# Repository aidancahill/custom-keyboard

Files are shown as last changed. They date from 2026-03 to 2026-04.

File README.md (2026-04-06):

# custom-keyboard

A 54-key split ergonomic keyboard with analog joysticks, shift register matrix scanning, and a Seeeduino XIAO nRF52840 BLE microcontroller. Designed from scratch using Ergogen, KiCad, and ZMK firmware.

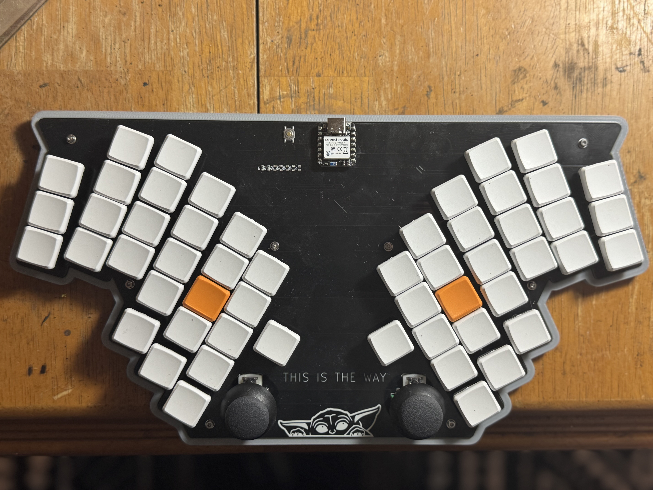
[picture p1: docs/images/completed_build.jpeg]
Completed Build

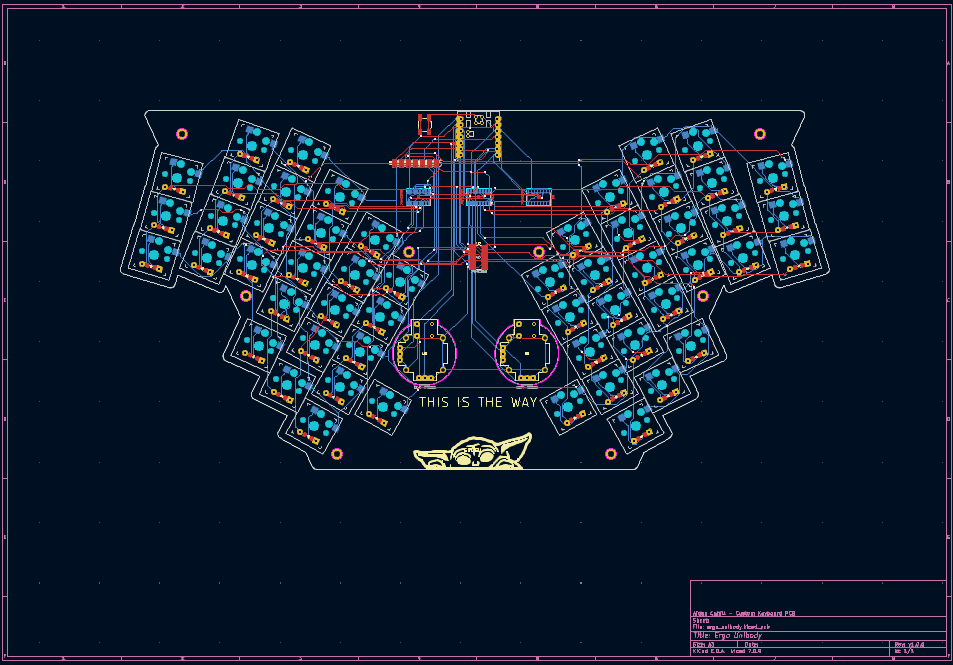
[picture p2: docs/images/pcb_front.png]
PCB Front

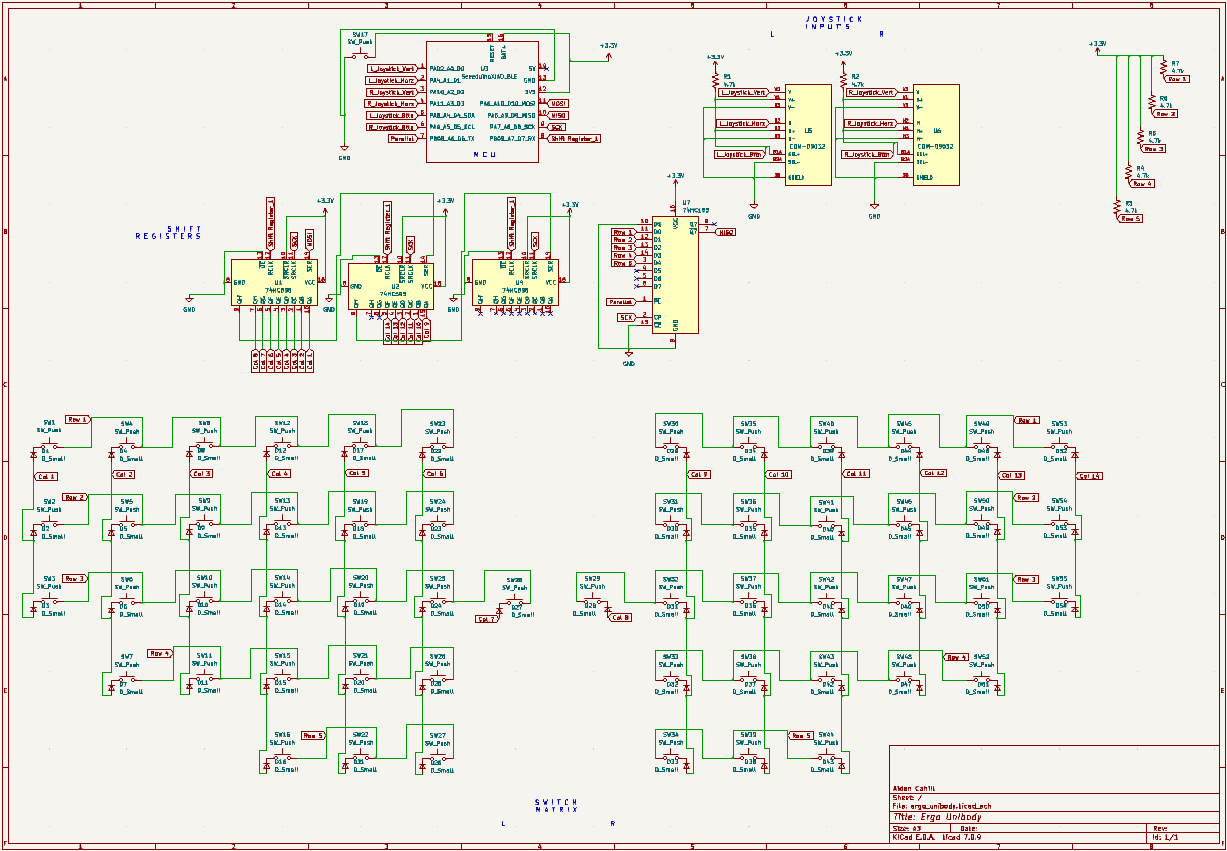
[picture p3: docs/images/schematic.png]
Schematic


## Features

- 54 Kailh Choc V1 low-profile keys with hotswap sockets
- Split ergonomic layout with column stagger and splay
- 2× analog joysticks (mouse movement + scroll)
- 74HC595 shift registers for column scanning (3× SIPO)
- 74HC165 shift register for row reading (1× PISO)
- Seeeduino XIAO nRF52840 BLE MCU
- 3D printed case with integrated bottom plate and heat-set inserts
- Custom Grogu silkscreen art

## Layout

```
Left half:                              Right half:
+---+---+---+---+---+---+              +---+---+---+---+---+---+
|Esc| 1 | 2 | 3 | 4 | 5 |              | 6 | 7 | 8 | 9 | 0 |Bks|
+---+---+---+---+---+---+              +---+---+---+---+---+---+
|Tab| Q | W | E | R | T |              | Y | U | I | O | P | \ |
+---+---+---+---+---+---+---+      +---+---+---+---+---+---+---+
| ` | A | S | D | F | G |Alt|      |Alt| H | J | K | L | ; | ' |
+---+---+---+---+---+---+---+      +---+---+---+---+---+---+---+
    | Z | X | C | V | B |              | N | M | , | . | / |
    +---+---+---+---+---+              +---+---+---+---+---+
            |Ctl|Shf|Spc|              |Fn |Shf|Ent|
            +---+---+---+              +---+---+---+

Fn Layer (hold Fn):
+---+---+---+---+---+---+              +---+---+---+---+---+---+
|F1 |F2 |F3 |F4 |F5 |F6 |              |F7 |F8 |F9 |F10|F11|F12|
+---+---+---+---+---+---+              +---+---+---+---+---+---+
| ~ | ! | @ | # | $ | % |              | ^ | & | * | ( | ) |Del|
+---+---+---+---+---+---+---+      +---+---+---+---+---+---+---+
|   | - | = | [ | ] | \ |   |      |   | ↓ | ← | ↑ | → |   |   |
+---+---+---+---+---+---+---+      +---+---+---+---+---+---+---+
    | _ | + | { | } | | |              |Hom|PgD|PgU|End|   |
    +---+---+---+---+---+              +---+---+---+---+---+
            |   |   |   |              |Fn |   |   |
            +---+---+---+              +---+---+---+

Shifted Symbols (Shift + key):
+---+---+---+---+---+---+              +---+---+---+---+---+---+
|   | ! | @ | # | $ | % |              | ^ | & | * | ( | ) |   |
+---+---+---+---+---+---+              +---+---+---+---+---+---+
|   |   |   |   |   |   |              |   |   |   |   |   | | |
+---+---+---+---+---+---+---+      +---+---+---+---+---+---+---+
| ~ |   |   |   |   |   |   |      |   |   |   |   |   | : | " |
+---+---+---+---+---+---+---+      +---+---+---+---+---+---+---+
    |   |   |   |   |   |              |   |   | < | > | ? |
    +---+---+---+---+---+              +---+---+---+---+---+
            |   |   |   |              |   |   |   |
            +---+---+---+              +---+---+---+
```

## Joystick Controls

| Joystick | Axis | Function |
|---|---|---|
| Right | Move | Mouse cursor |
| Right | Click | Left click |
| Left | Move | Scroll |
| Left | Click | Right click |

## Repository Structure

```
custom-keyboard/
├── pcb/                  KiCad schematic, PCB, and gerbers
├── case/
│   └── stl/              Print-ready STL file
├── ergogen/              Original Ergogen layout config
├── firmware/             Link to ZMK firmware repo
└── docs/                 Build guide, BOM, and photos
```

## Quick Start

1. **Order PCBs** — upload `pcb/gerbers/` to JLCPCB or PCBWay (2-layer, 1.6mm, any color)
2. **Order components** — see [BOM](docs/bom.md)
3. **3D print case** — slice `case/stl/case_3mm_bottom.stl` (PETG, 50% infill)
4. **Solder** — follow the [build guide](docs/build_guide.md)
5. **Flash firmware** — see [firmware/README.md](firmware/README.md)

## Pin Mapping

| XIAO Pin | Function |
|---|---|
| D0 (A0) | Left Joystick Vertical (ADC) |
| D1 (A1) | Left Joystick Horizontal (ADC) |
| D2 (A2) | Right Joystick Vertical (ADC) |
| D3 (A3) | Right Joystick Horizontal (ADC) |
| D4 | Left Joystick Button |
| D5 | Right Joystick Button |
| D6 | 74HC165 PL (parallel load) |
| D7 | 74HC595 RCLK (latch) |
| D8 | SCK (shared SPI clock) |
| D9 | MISO (74HC165 serial data) |
| D10 | MOSI (74HC595 serial data) |

## Matrix Architecture

The keyboard uses a 14-column × 5-row matrix:

- **Columns** are driven by 3× daisy-chained 74HC595 shift registers (serial-in, parallel-out) via SPI MOSI
- **Rows** are read by 1× 74HC165 shift register (parallel-in, serial-out) via SPI MISO
- **Diodes** (1N4148W SOD-123) prevent ghosting, oriented column-to-row
- All shift registers share the SPI clock (SCK), with separate CS/latch pins

## Firmware

ZMK firmware lives in a separate repo: **[custom-keyboard ZMK firmware](https://github.com/aidancahill/custom-keyboard-zmk-firmware)**

Custom ZMK modules include:

- `zmk,gpio-165` — 74HC165 PISO shift register GPIO input driver
- `zmk,input-analog-joystick` — analog joystick pointing device driver

## Design Tools

- **Layout**: [Ergogen](https://ergogen.xyz)
- **PCB**: [KiCad 7](https://www.kicad.org)
- **Routing**: [FreeRouting](https://freerouting.org)
- **Case**: [OpenJSCAD](https://openjscad.xyz)
- **Firmware**: [ZMK](https://zmk.dev)

## Resources & Acknowledgments

| Resource | Description |
|---|---|
| [Ergogen Web UI](https://ergogen.cache.works/) | Browser-based Ergogen layout editor |
| [Ergogen](https://github.com/ergogen/ergogen) | Ergonomic keyboard generator framework |
| [Cantor Keyboard](https://github.com/diepala/cantor) | Split keyboard reference design |
| [Triboard](https://github.com/tarneaux/triboard) | Split keyboard reference design |
| [Kiai Split](https://github.com/makgyber/kiai-split) | Split keyboard reference design |
| [Awesome Split Keyboards](https://github.com/diimdeep/awesome-split-keyboards) | Curated list of split keyboard projects |
| [TOTEM Keyboard](https://github.com/GEIGEIGEIST/TOTEM) | Split keyboard with XIAO BLE support |
| [FlatFootFox](https://flatfootfox.com/) | Ergogen and keyboard design tutorials |
| [Getting Started with Keyboard PCBs](https://brianlow.notion.site/Getting-Started-5c18955a43044c5f98100212e83c19ef) | PCB design guide for keyboards |
| [The Keyboard Matrix](https://www.dairequinlan.com/2020/12/the-keyboard-part-2-the-matrix/) | How keyboard matrices work |
| [74HC595 Shift Register Tutorial](https://lastminuteengineers.com/74hc595-shift-register-arduino-tutorial) | 74HC595 wiring and code tutorial |
| [74HC595 Keyboard Build](https://mehmedbasic.dk/post/74hc595-keyboard/) | Using shift registers in keyboards |
| [Keyboard Layout Editor](https://www.keyboard-layout-editor.com/#/) | Visual keyboard layout designer |

## License

MIT

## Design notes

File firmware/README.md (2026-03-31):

# Firmware

The ZMK firmware for this keyboard lives in a separate repository to enable GitHub Actions builds:

**[custom-keyboard ZMK firmware](https://github.com/aidancahill/custom-keyboard-zmk-firmware)**

## Flashing

1. Download `zmk.uf2` from the latest GitHub Actions build artifact
2. Double-tap the reset button on the XIAO BLE — a USB drive appears
3. Drag `zmk.uf2` onto the drive
4. Board reboots with new firmware

## Custom ZMK Modules

The firmware repo includes two custom drivers:

- **`zmk,gpio-165`** — 74HC165 PISO shift register driver for reading matrix rows via SPI
- **`zmk,input-analog-joystick`** — Analog joystick driver for mouse cursor and scroll input

## Modifying the Keymap

Edit `config/custom-keyboard.keymap` in the firmware repo. Push to `main` and GitHub Actions will build a new `.uf2` automatically.

See the [ZMK keymap documentation](https://zmk.dev/docs/keymaps) for available behaviors and keycodes.

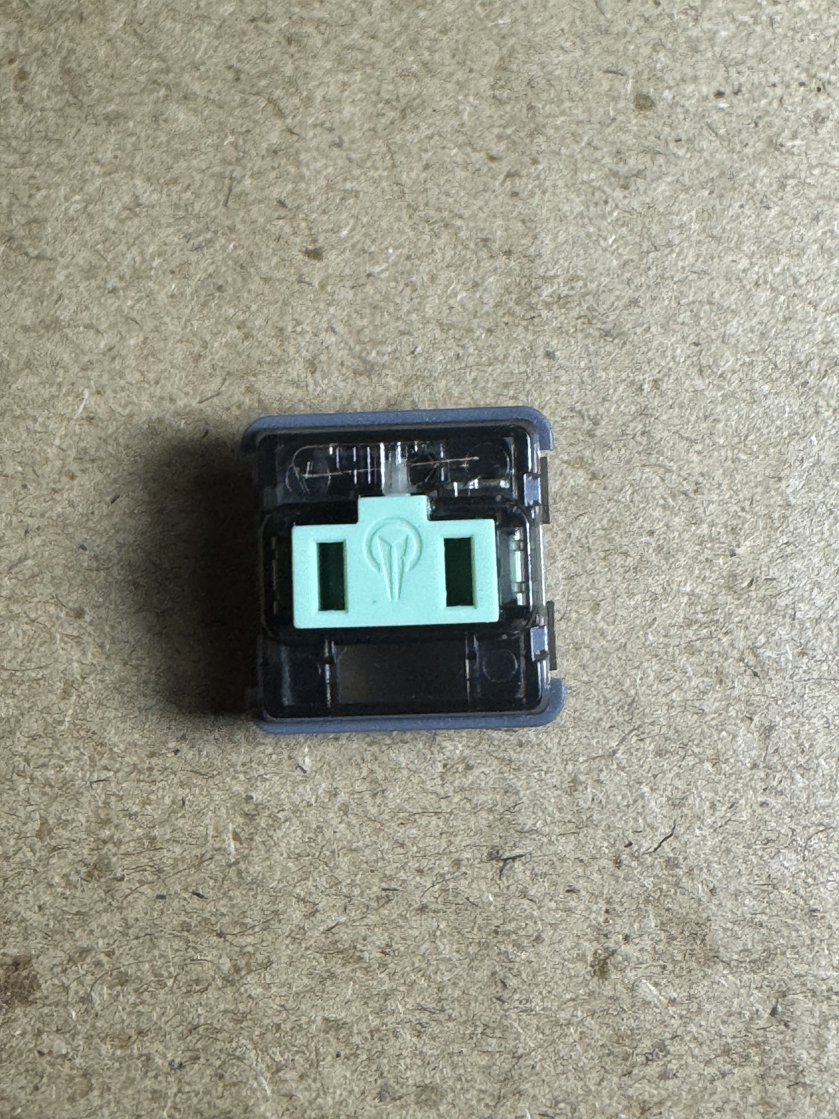
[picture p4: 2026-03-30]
docs/images/kalih_ch-co_twighlight.jpeg

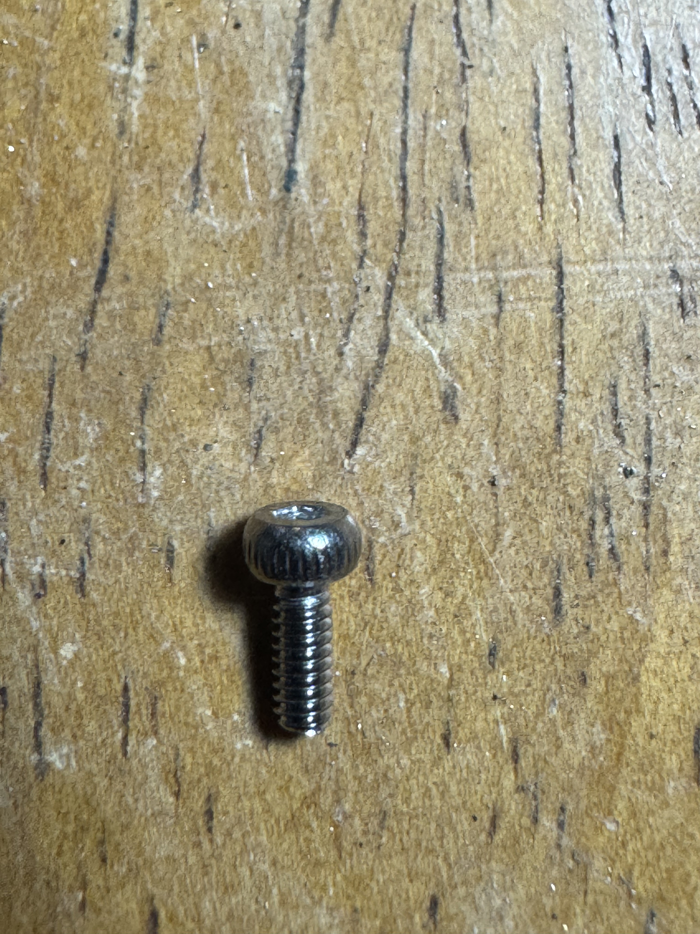
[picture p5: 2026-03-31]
docs/images/m2_screw.jpeg

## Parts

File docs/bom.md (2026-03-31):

# Bill of Materials

## Electronics

| Qty | Component | Package | Part Number | Source | Est. Price |
|-----|---|---|---|---|---|
| 54 | Kailh Choc V1 hotswap sockets | — | — | LowproKB | $10.50 |
| 60 | Ambients Silent Twilight switches (or any Choc V1) | PG1350 | — | LowproKB | $78.00 |
| 54 | MBK 1u keycaps | Choc V1 | — | LowproKB | $21.00 × 6 |
| 2 | MBK homing keycaps | Choc V1 | — | LowproKB | $1.10 |
| 54 | 1N4148W diodes | SOD-123 | 1N4148W-13-F | DigiKey | ~$5 |
| 3 | 74HC595 shift registers | SOIC-16 | SN74HC595DR | DigiKey | ~$3 |
| 1 | 74HC165 shift register | SOIC-16 | SN74HC165DR | DigiKey | ~$1 |
| 7 | 10kΩ resistors | 0805 SMD | — | Amazon | $5 |
| 1 | Seeeduino XIAO nRF52840 BLE (pre-soldered) | — | 102010631-FA | Amazon | $18 |
| 2 | COM-09032 joysticks | — | COM-09032 | SparkFun | ~$10 |
| 1 | TL3342 reset button | SMD | — | DigiKey | ~$1 |
| 2 | 7-pin 2.54mm female header sockets | Through-hole | — | Amazon | $9 (25-pack) |

## Hardware

| Qty | Component | Spec | Source | Est. Price |
|-----|---|---|---|---|
| 8+ | M2 heat-set brass inserts | M2 × 4mm | Amazon (ruthex) | ~$8 (70-pack) |
| 8 | M2 socket head cap screws | M2 × 5mm | Amazon | ~$8 |

## PCB

| Item | Spec |
|---|---|
| Layers | 2 |
| Thickness | 1.6mm |
| Surface finish | HASL or ENIG |
| Solder mask | Any color (black recommended) |
| Silkscreen | White |
| Min track/spacing | 6/6 mil |
| Min hole size | 0.3mm |

Order from JLCPCB or PCBWay. Upload the gerber zip from `pcb/gerbers/`. Minimum order is usually 5 boards.

## 3D Printed Case

| Item | File | Material | Settings |
|---|---|---|---|
| Case (with integrated 3mm bottom) | `case/stl/hollow_case.stl` | PETG or PLA | 50% infill, 0.2mm layer height |

Print yourself or order from PCBWay's 3D printing service.

## Tools Required

- Soldering iron with fine tip (conical or chisel)
- Tweezers (angled tip preferred)
- Flux (pen or paste)
- Solder wire (0.5-0.8mm diameter, leaded recommended for beginners)
- Solder wick (for fixing mistakes)
- Isopropyl alcohol 91%+ (for cleaning flux)
- Toothbrush (for scrubbing flux)
- Soldering iron (for heat-set inserts)

## Estimated Total Cost

| Category | Cost |
|---|---|
| Switches + keycaps | ~$115 |
| Electronics (diodes, ICs, MCU, headers) | ~$45 |
| PCB (5 pcs) | ~$15-25 |
| 3D printed case | ~$10-30 |
| Hardware (screws, inserts) | ~$16 |
| **Total** | **~$200-230** |

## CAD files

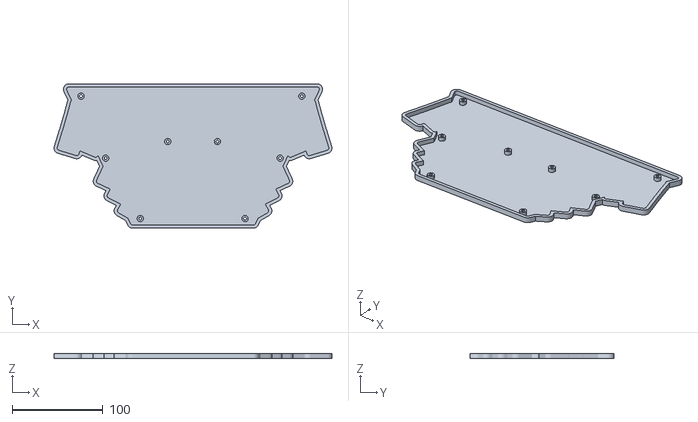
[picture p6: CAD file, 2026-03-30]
case/stl/hollow_case.stl
307.0 x 159.4 x 5.60

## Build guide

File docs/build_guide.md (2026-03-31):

# Build Guide

## Before You Start

Make sure you have all components from the [BOM](bom.md) and the tools listed there. Read through the entire guide before soldering.

## Step 1: Inspect the PCB

Check both sides of the bare PCB for any defects — scratches on traces, bridged pads, or missing solder mask. The front side has switch holes and the Grogu silkscreen. The back side is where most SMD components go.

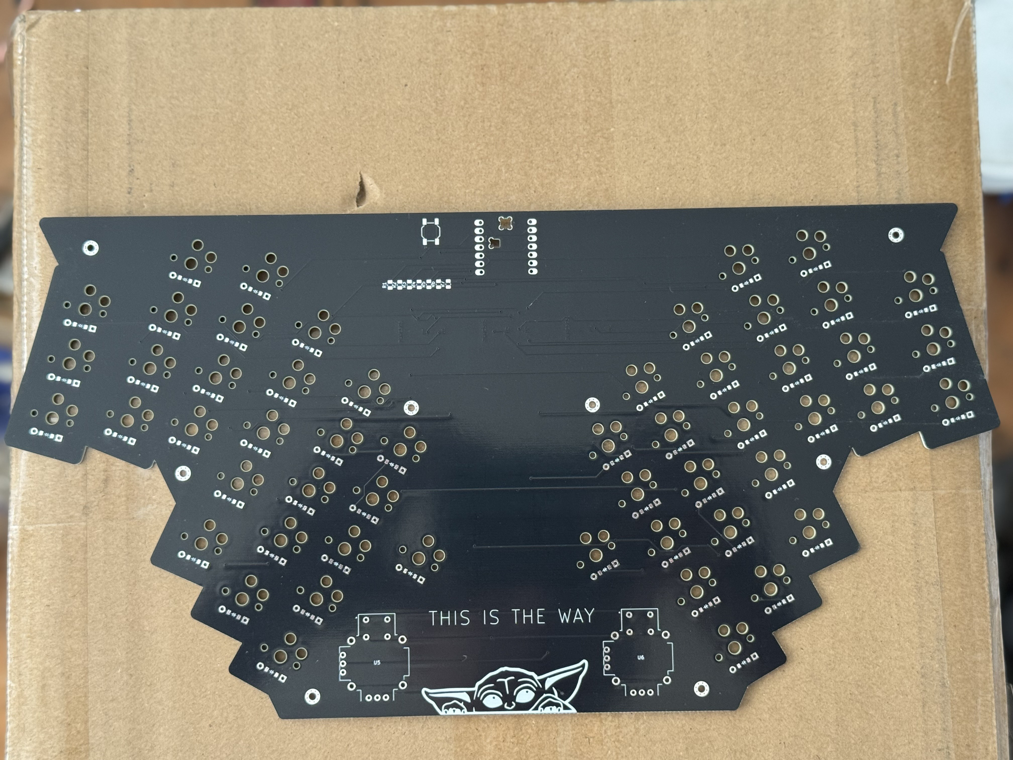
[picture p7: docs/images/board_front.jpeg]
PCB Front

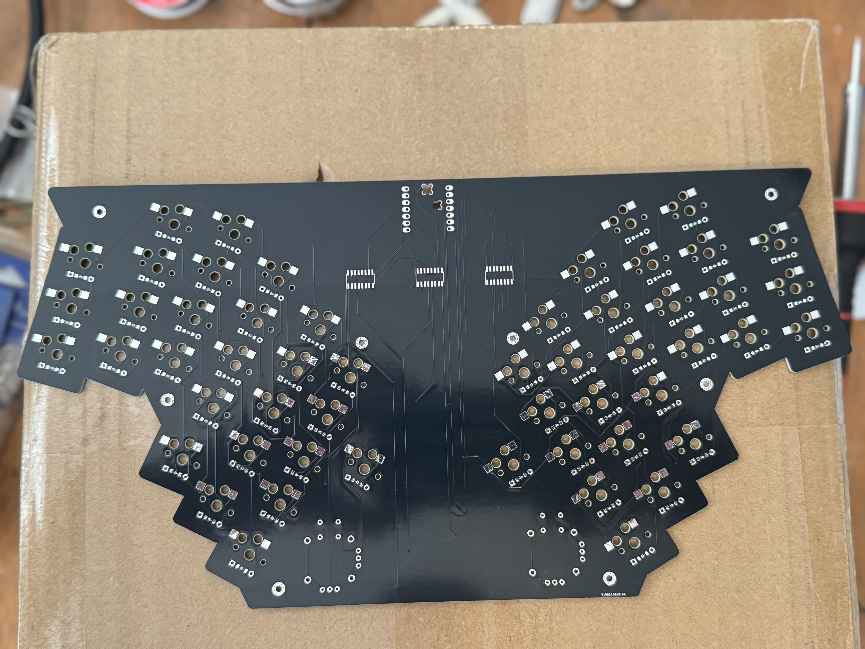
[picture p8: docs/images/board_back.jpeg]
PCB Back


## Step 2: Solder SMD Components (Back Side)

Work on the **back of the PCB** first. Solder in this order:

### 2a: Diodes (54×)

The 1N4148W SOD-123 diodes have a **polarity line** — match it to the silkscreen marking on the PCB.

Technique:

1. Apply flux to both pads
2. Tin one pad with a small blob of solder
3. Hold the diode with tweezers, reheat the tinned pad, slide the diode in
4. Check alignment, then solder the second pad
5. Reflow the first pad if needed

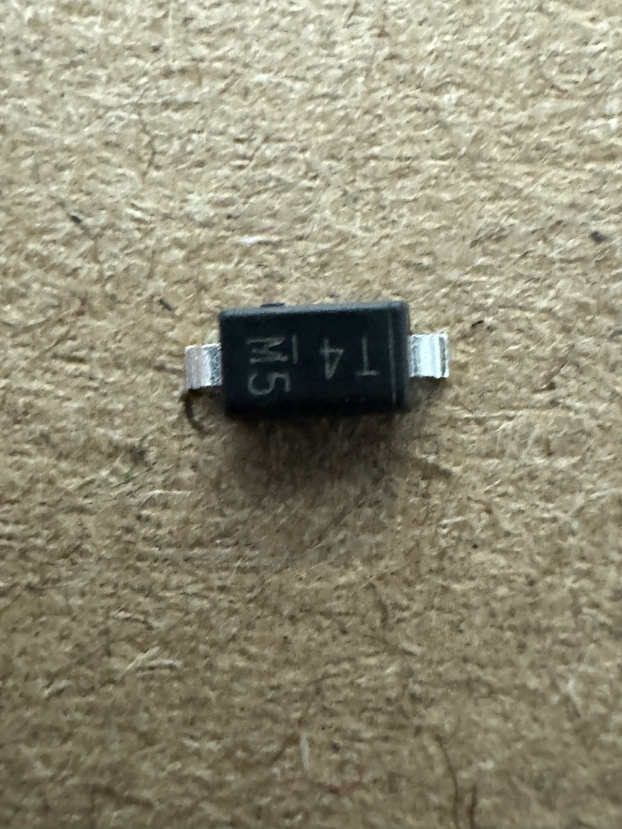
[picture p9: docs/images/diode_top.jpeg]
Diode Top

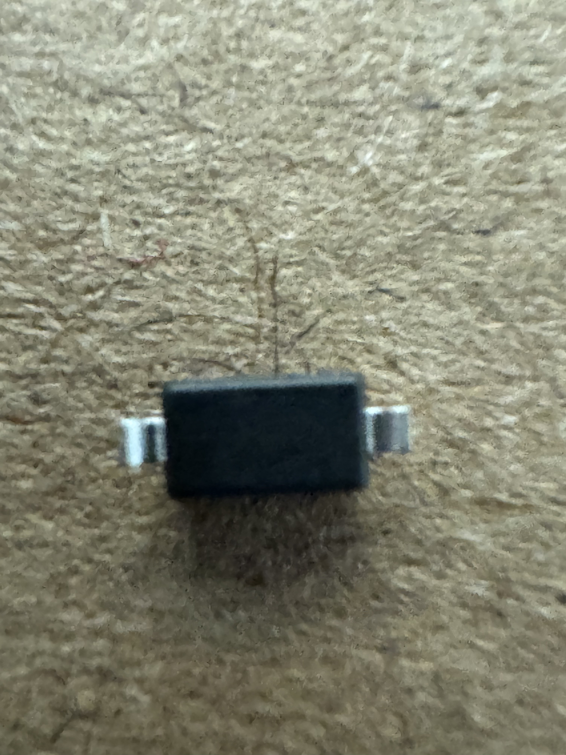
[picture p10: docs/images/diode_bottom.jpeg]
Diode Bottom


### 2b: Shift Registers (4×)

Three 74HC595 (column drivers) and one 74HC165 (row reader), all SOIC-16.

1. Apply flux along all pads
2. Align pin 1 (dot on chip) with pin 1 marking on PCB
3. Tin one corner pad to tack the chip down
4. Verify all pins are aligned with pads
5. Drag solder across the remaining pins with plenty of flux
6. Clean up any bridges with solder wick

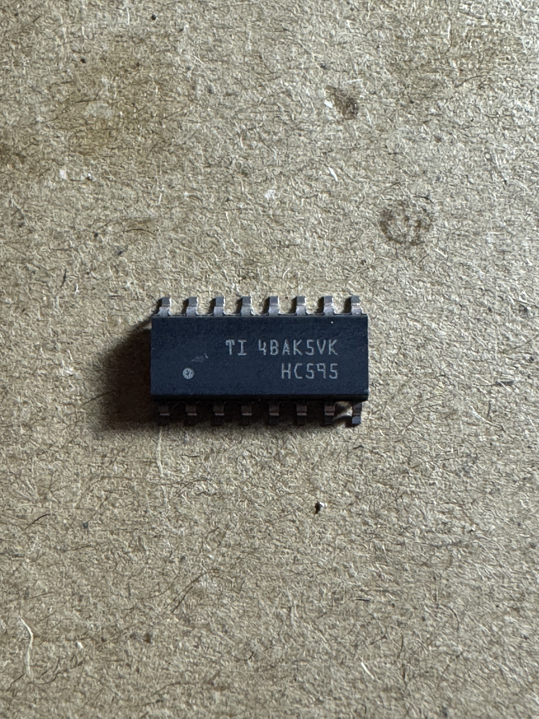
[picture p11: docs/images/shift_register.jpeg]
Shift Register


### 2c: Resistors (7×)

The 10kΩ 0805 resistors have **no polarity** — orientation doesn't matter. Same technique as diodes.

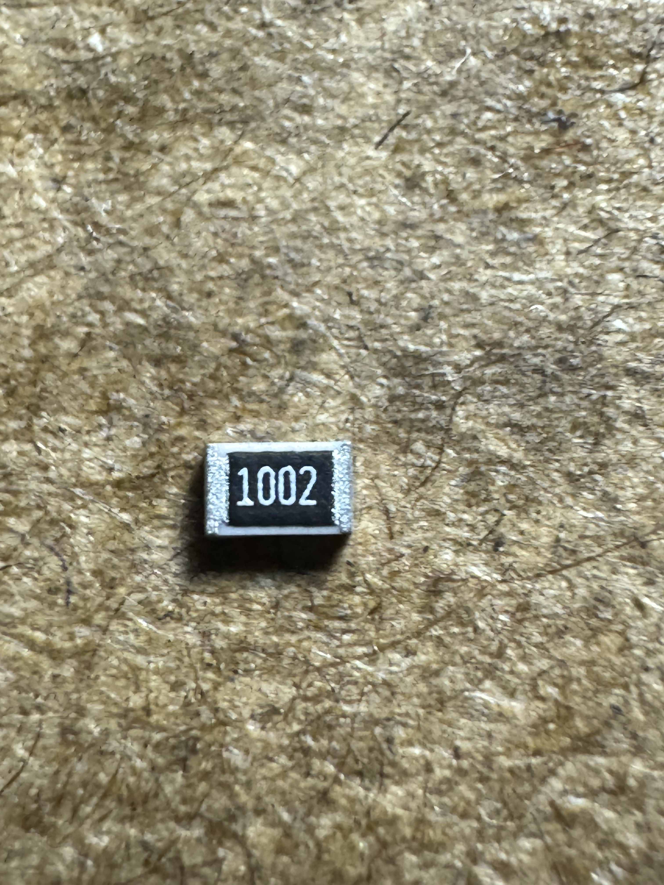
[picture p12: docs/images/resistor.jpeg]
Resistor


### 2d: Reset Button

Solder the TL3342 reset button. Align with the pads and solder.

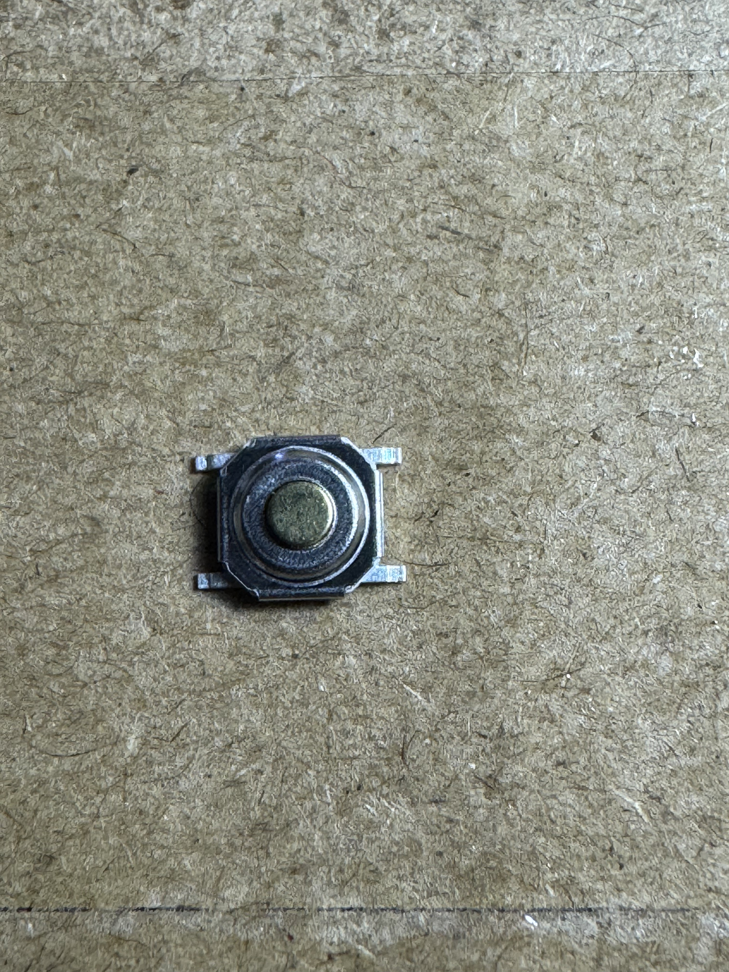
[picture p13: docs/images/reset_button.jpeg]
Reset Button


### 2e: Hotswap Sockets (54×)

Solder the Kailh Choc hotswap sockets onto the back side. Make sure they're seated flat against the PCB. These have a specific orientation — the socket opening should align with the switch pin holes.

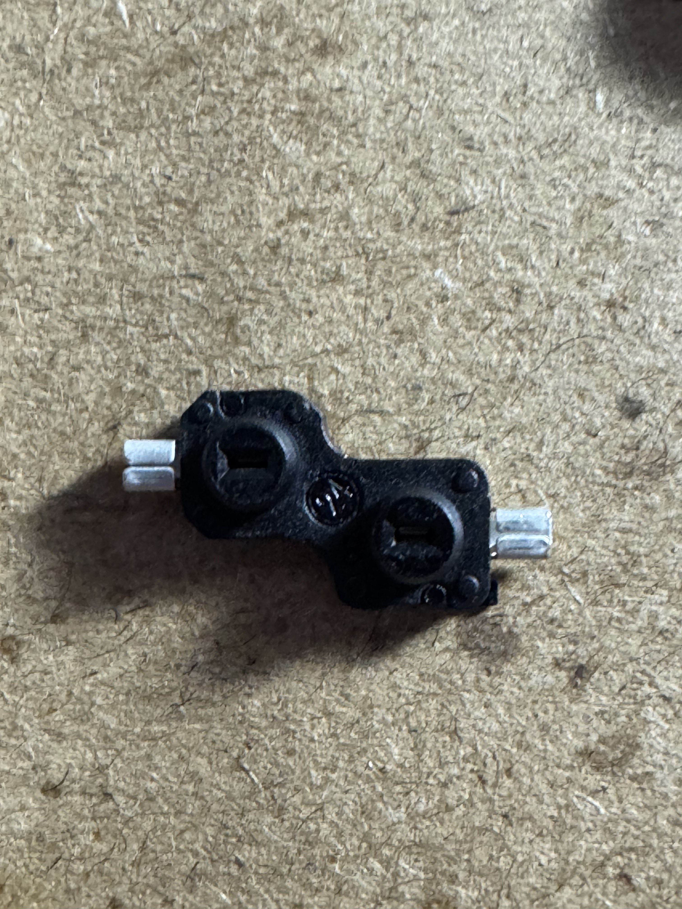
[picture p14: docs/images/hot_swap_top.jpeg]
Hot Swap Socket Top

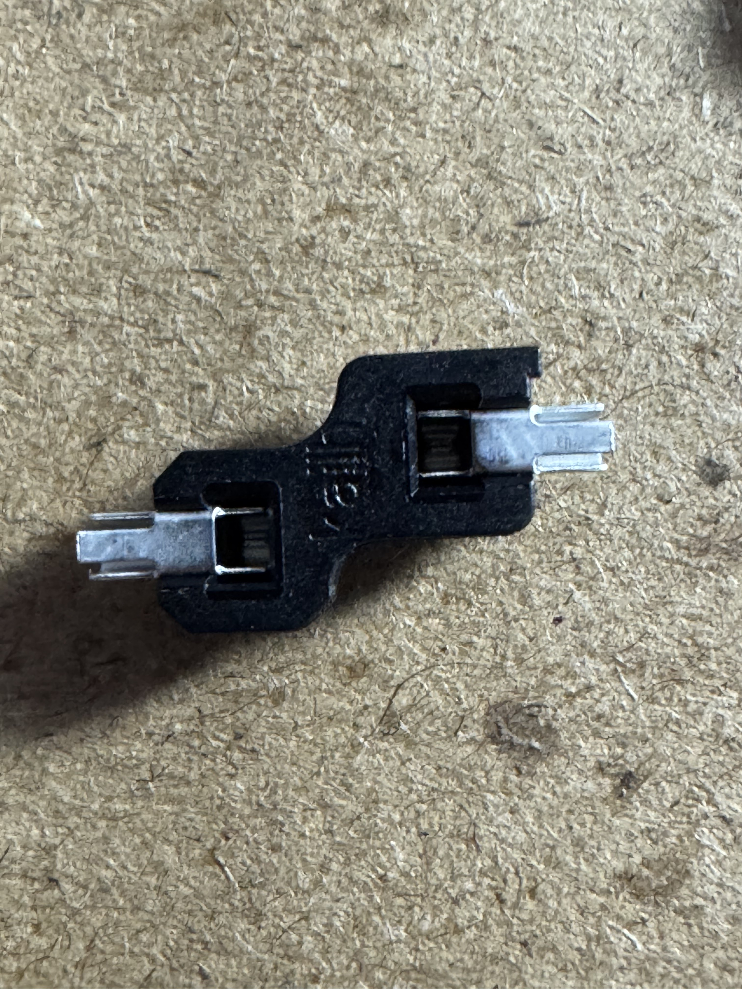
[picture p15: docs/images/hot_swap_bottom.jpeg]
Hot Swap Socket Bottom


## Step 3: Clean the PCB

Scrub all flux residue with a toothbrush and 91% isopropyl alcohol. Let air dry.

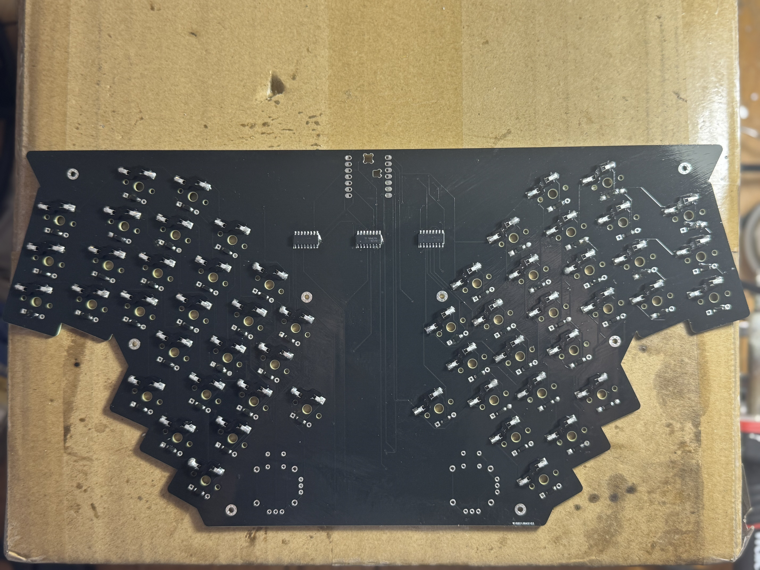
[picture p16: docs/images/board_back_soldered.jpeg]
PCB Back


## Step 4: Solder Headers (Front Side)

Flip the board to the **front side**.

1. Solder two 7-pin female headers to the U3 (XIAO MCU) footprint
2. The XIAO BLE (pre-soldered with male headers) will plug into these later

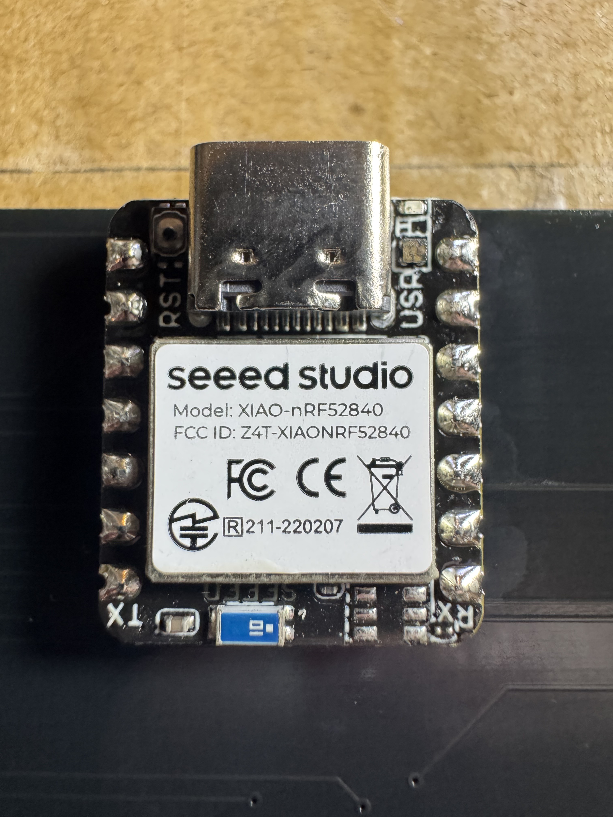
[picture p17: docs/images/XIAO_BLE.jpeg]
XIAO MCU


## Step 5: Test Before Proceeding

Before installing switches, plug in the XIAO and flash the test firmware to verify the matrix works. See the firmware repo for the test scanner script. Press each key position with tweezers across the hotswap socket pins to simulate key presses.

## Step 6: Install Switches

Insert all 54 Choc V1 switches into the hotswap sockets from the **front side**. They should click in firmly. Make sure the pins are straight before pressing — bent pins won't seat into the sockets.

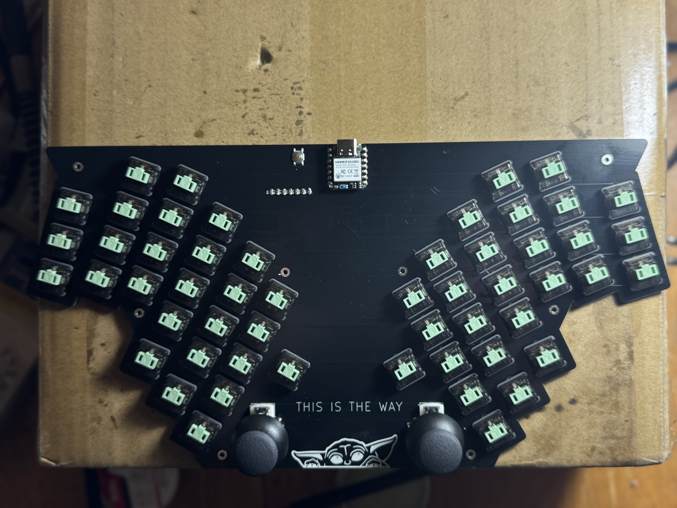
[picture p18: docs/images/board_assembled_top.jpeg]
Front Assembled


## Step 7: Install Keycaps

Press the MBK keycaps onto each switch stem. Place the two homing keycaps on the home row index finger positions (F and J equivalent).

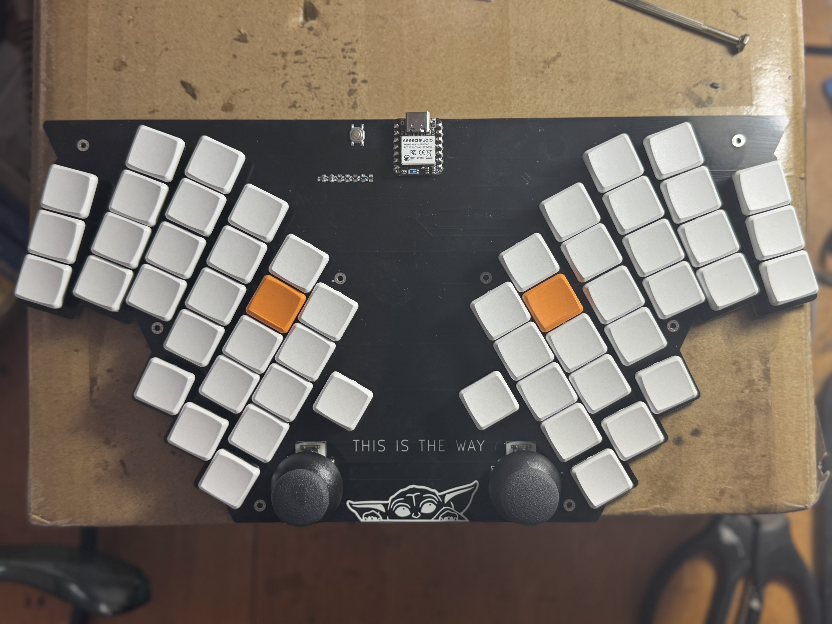
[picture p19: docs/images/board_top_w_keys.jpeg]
Board w/ Keys


## Step 8: Prepare the Case

### Heat-Set Inserts

1. Heat your soldering iron to ~200-220°C
2. Place an M2 brass insert on each standoff hole in the case
3. Press the hot iron tip onto the insert — it will slowly melt into the plastic
4. Keep it straight and stop when it's flush with the surface
5. Repeat for all 8 mounting holes

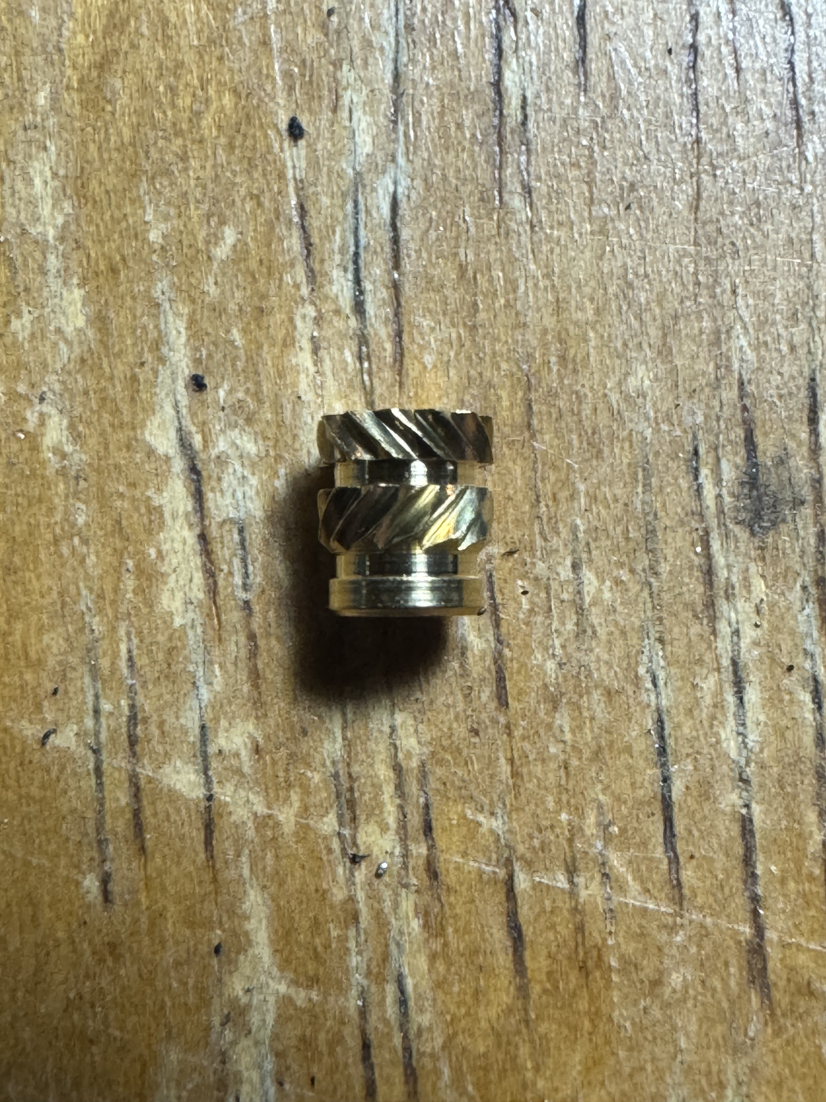
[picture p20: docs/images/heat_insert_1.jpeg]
Heat Insert Side

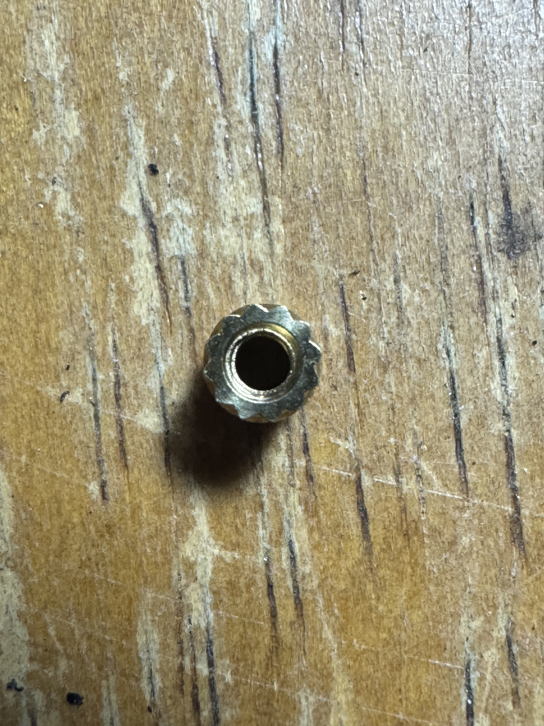
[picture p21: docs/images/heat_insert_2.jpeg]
Heat Insert Top

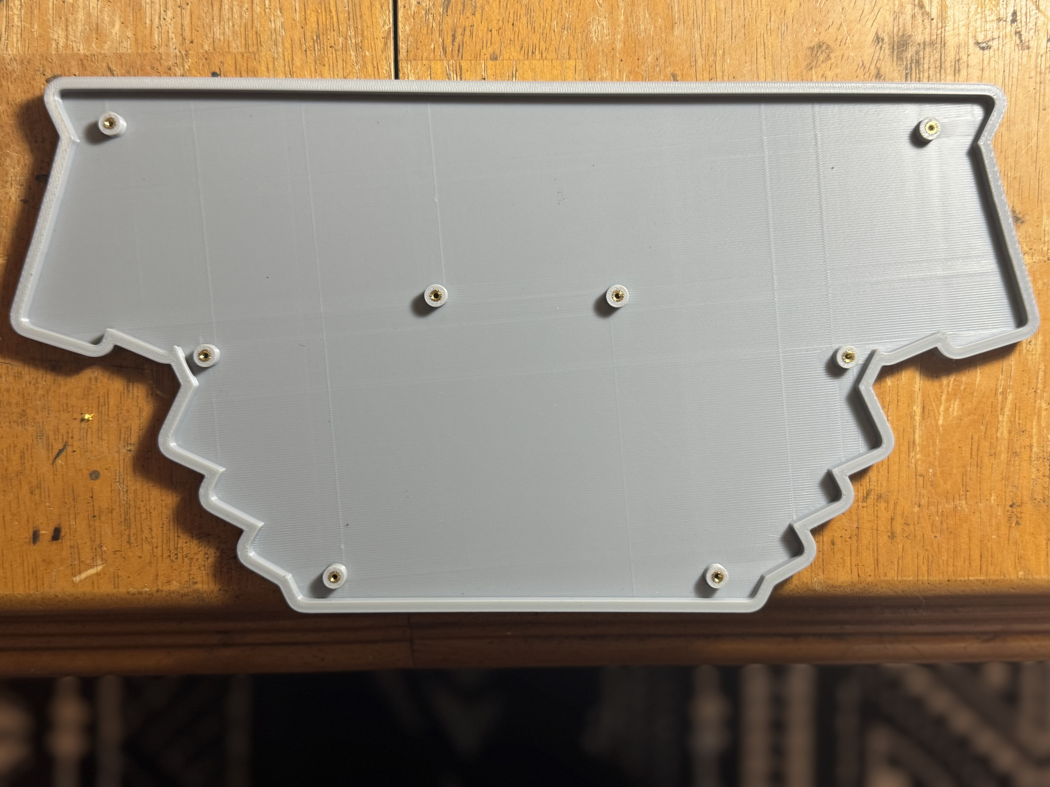
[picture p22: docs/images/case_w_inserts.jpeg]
Case w/ Inserts


### Install Joysticks

If using the v2 PCB with joystick support, solder the COM-09032 joysticks to the front side of the PCB before mounting in the case.

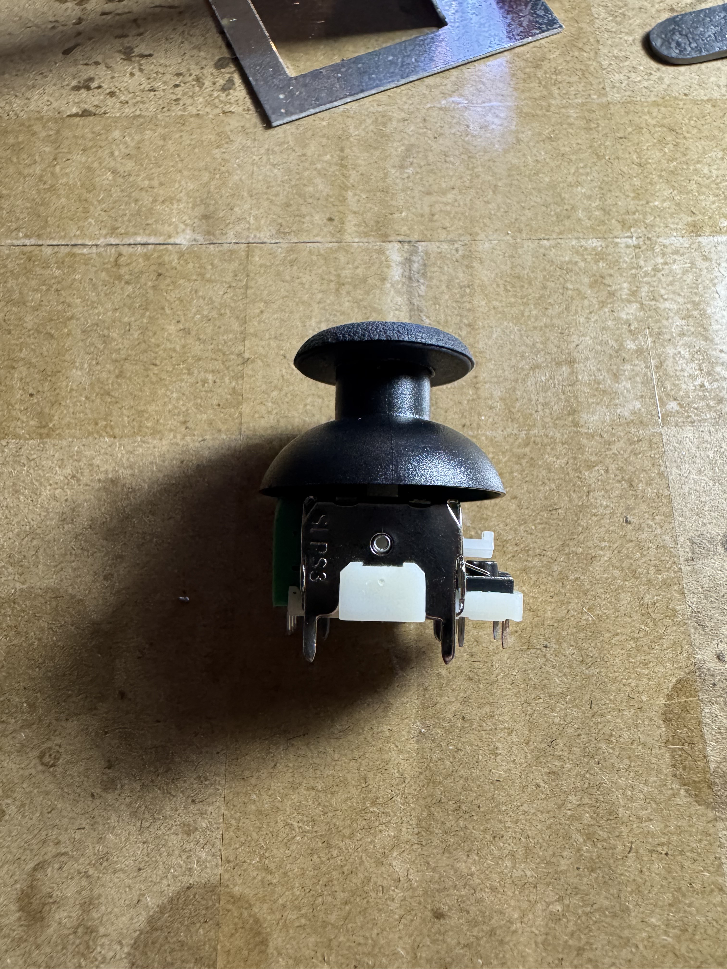
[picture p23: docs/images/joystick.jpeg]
Joystick


## Step 9: Mount PCB in Case

1. Place the PCB into the case, aligning the mounting holes with the inserts
2. Secure with M2 × 5mm screws — don't overtighten

Completed Build

## Step 10: Plug In MCU and Flash

ZMK firmware lives in a separate repo: **[custom-keyboard ZMK firmware](https://github.com/aidancahill/custom-keyboard-zmk-firmware)**

1. Plug the XIAO BLE into the female headers
2. Connect USB-C cable to computer
3. Double-tap the reset button to enter bootloader mode
4. Drag the `zmk.uf2` firmware file onto the USB drive
5. The board will reboot with the keyboard firmware

## Step 11: Test All Keys

Open a text editor and press every key to verify they all work. If a key doesn't register:

- Check the diode solder joint at that position
- Check the hotswap socket solder joints
- Make sure the switch is fully seated

## Troubleshooting

### All keys in a column don't work

Check the solder joint on the corresponding 74HC595 output pin. Reflow with flux.

### All rows read as pressed

The pull-up resistors R3-R7 need to be removed. The firmware uses internal pull-downs instead.

### No keys register at all

- Verify the XIAO is getting power (LED on)
- Check SCK, MOSI, and RCLK solder joints on both the XIAO and shift registers
- Verify the shift registers have +3.3V and GND

### Single dead key

Reflow the diode at that key position. Add flux, reheat both pads for 2-3 seconds each.

### Solder won't stick to pad

- Add flux to the pad
- Clean the pad with isopropyl alcohol or a pencil eraser
- Make sure the iron tip is clean and tinned
- Heat the pad first, then apply solder to the pad (not the iron)

### Joystick not responding

- Verify the joystick analog signals are routed to XIAO D0-D3 (ADC pins)
- Check the 74HC165 is installed (not another 74HC595)
- Verify D6 connects to the 74HC165 PL pin
- Verify D9 connects to the 74HC165 Q7 pin

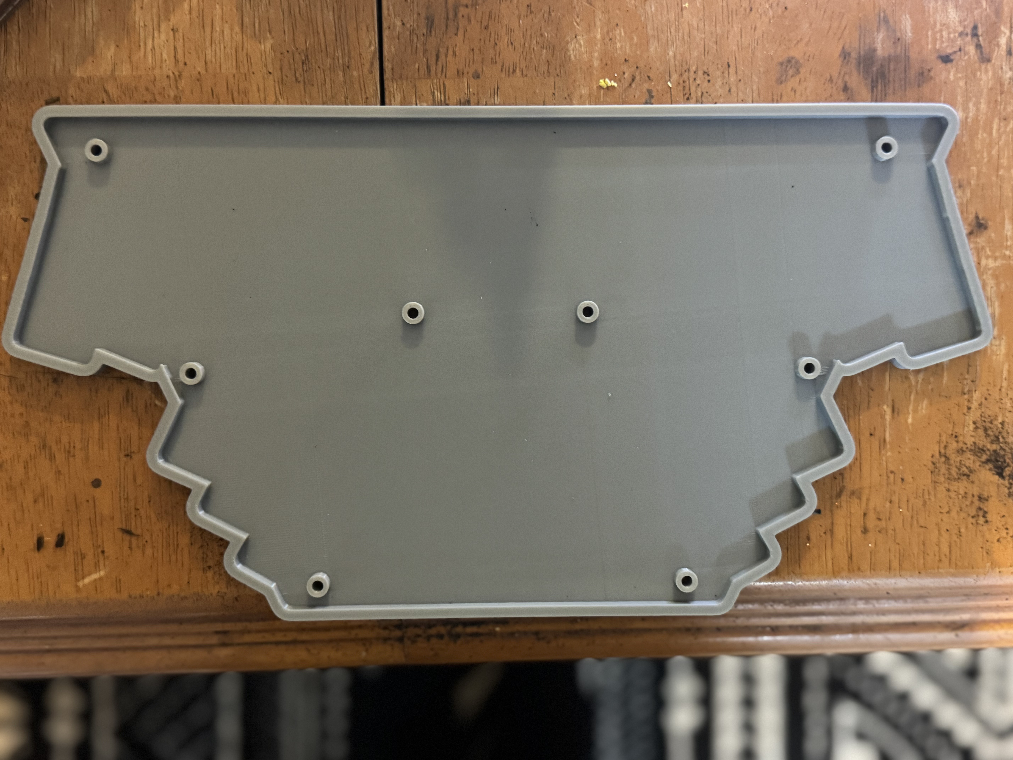
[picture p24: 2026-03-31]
docs/images/3d_printed_case.jpeg

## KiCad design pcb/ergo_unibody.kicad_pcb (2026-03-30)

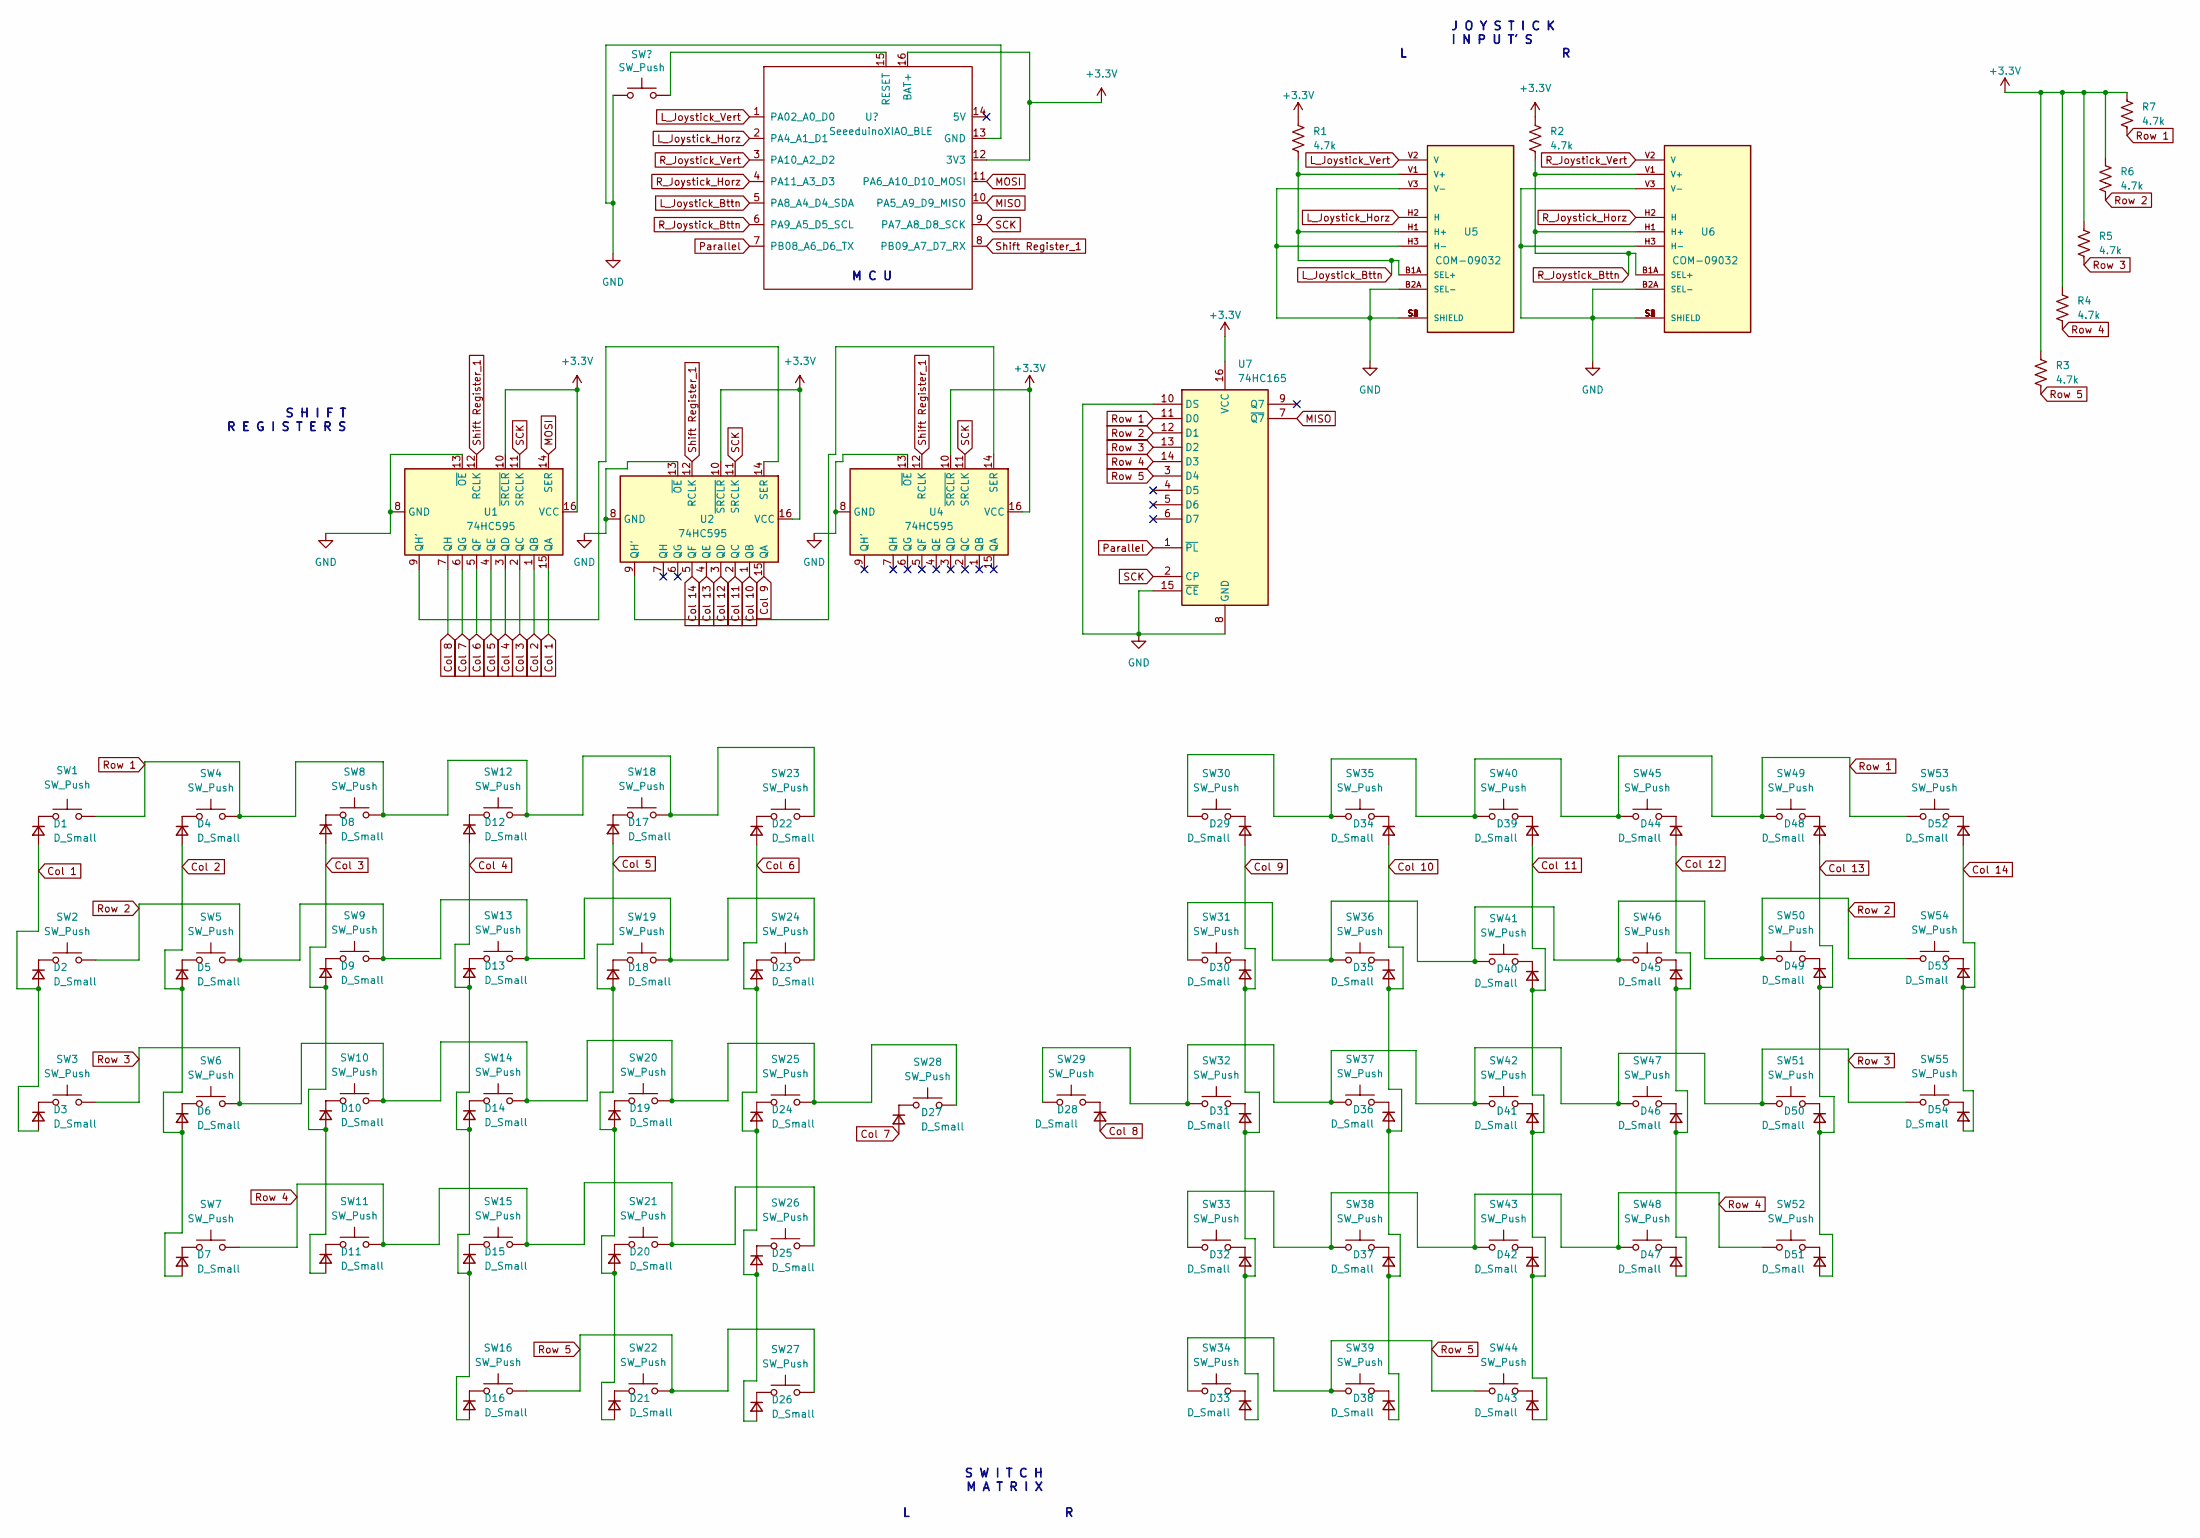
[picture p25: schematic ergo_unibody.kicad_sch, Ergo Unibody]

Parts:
D1, D2, D3, D4, D5, D6, D7, D8, D9, D10, D11, D12, D13, D14, D15, D16, D17, D18, D19, D20, D21, D22, D23, D24, D25, D26, D27, D28, D29, D30, D31, D32, D33, D34, D35, D36, D37, D38, D39, D40, D41, D42, D43, D44, D45, D46, D47, D48, D49, D50, D51, D52, D53, D54: D_Small; Diode_SOD123
R1, R2, R3, R4, R5, R6, R7: 4.7k; R_0805_2012Metric
SW1, SW2, SW3, SW4, SW5, SW6, SW7, SW8, SW9, SW10, SW11, SW12, SW13, SW14, SW15, SW16, SW18, SW19, SW20, SW21, SW22, SW23, SW24, SW25, SW26, SW27, SW28, SW29, SW30, SW31, SW32, SW33, SW34, SW35, SW36, SW37, SW38, SW39, SW40, SW41, SW42, SW43, SW44, SW45, SW46, SW47, SW48, SW49, SW50, SW51, SW52, SW53, SW54, SW55: SW_Push; Kailh_socket_PG1350_optional
SW17: SW_Push; SW_SPST_TL3342; LCSC Part Number C79174
U1, U2, U4: 74HC595; SOIC-16_3.9x9.9mm_P1.27mm
U3: SeeeduinoXIAO_BLE; xiao-ble-smd-cutout
U5, U6: COM-09032; XDCR_COM-09032; PARTREV N/A
U7: 74HC165; SOIC-16_3.9x9.9mm_P1.27mm

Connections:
+3.3V: R1.1, R2.1, R3.1, R4.1, R5.1, R6.1, R7.1, U1.10 (~SRCLR), U1.16 (VCC), U2.10 (~SRCLR), U2.16 (VCC), U3.12 (3V3), U3.16 (BAT+), U4.10 (~SRCLR), U4.16 (VCC), U7.16 (VCC)
Col 1: D1.2 (A), D2.2 (A), D3.2 (A), U1.15 (QA)
Col 2: D4.2 (A), D5.2 (A), D6.2 (A), D7.2 (A), U1.1 (QB)
Col 3: D8.2 (A), D9.2 (A), D10.2 (A), D11.2 (A), U1.2 (QC)
Col 4: D12.2 (A), D13.2 (A), D14.2 (A), D15.2 (A), D16.2 (A), U1.3 (QD)
Col 5: D17.2 (A), D18.2 (A), D19.2 (A), D20.2 (A), D21.2 (A), U1.4 (QE)
Col 6: D22.2 (A), D23.2 (A), D24.2 (A), D25.2 (A), D26.2 (A), U1.5 (QF)
Col 7: D27.2 (A), U1.6 (QG)
Col 8: D28.2 (A), U1.7 (QH)
Col 9: D29.2 (A), D30.2 (A), D31.2 (A), D32.2 (A), D33.2 (A), U2.15 (QA)
Col 10: D34.2 (A), D35.2 (A), D36.2 (A), D37.2 (A), D38.2 (A), U2.1 (QB)
Col 11: D39.2 (A), D40.2 (A), D41.2 (A), D42.2 (A), D43.2 (A), U2.2 (QC)
Col 12: D44.2 (A), D45.2 (A), D46.2 (A), D47.2 (A), U2.3 (QD)
Col 13: D48.2 (A), D49.2 (A), D50.2 (A), D51.2 (A), U2.4 (QE)
Col 14: D52.2 (A), D53.2 (A), D54.2 (A), U2.5 (QF)
GND: SW17.2, U1.8 (GND), U1.13 (~OE), U2.8 (GND), U2.13 (~OE), U3.13 (GND), U4.8 (GND), U4.13 (~OE), U5.B2A (SEL-), U5.H3 (H-), U5.S1 (SHIELD), U5.S2 (SHIELD), U5.S3 (SHIELD), U5.S4 (SHIELD), U5.V3 (V-), U6.B2A (SEL-), U6.H3 (H-), U6.S1 (SHIELD), U6.S2 (SHIELD), U6.S3 (SHIELD), U6.S4 (SHIELD), U6.V3 (V-), U7.8 (GND), U7.10 (DS), U7.15 (~CE)
L_Joystick_Bttn: R1.2, U3.5 (PA8_A4_D4_SDA), U5.B1A (SEL+), U5.H1 (H+), U5.V1 (V+)
L_Joystick_Horz: U3.2 (PA4_A1_D1), U5.H2 (H)
L_Joystick_Vert: U3.1 (PA02_A0_D0), U5.V2 (V)
MISO: U3.10 (PA5_A9_D9_MISO), U7.7 (~Q7)
MOSI: U1.14 (SER), U3.11 (PA6_A10_D10_MOSI)
unnamed: D1.1 (K), SW1.1
unnamed: D2.1 (K), SW2.1
unnamed: D3.1 (K), SW3.1
unnamed: D4.1 (K), SW4.1
unnamed: D5.1 (K), SW5.1
unnamed: D6.1 (K), SW6.1
unnamed: D7.1 (K), SW7.1
unnamed: D8.1 (K), SW8.1
unnamed: D9.1 (K), SW9.1
unnamed: D10.1 (K), SW10.1
unnamed: D11.1 (K), SW11.1
unnamed: D12.1 (K), SW12.1
unnamed: D13.1 (K), SW13.1
unnamed: D14.1 (K), SW14.1
unnamed: D15.1 (K), SW15.1
unnamed: D16.1 (K), SW16.1
unnamed: D17.1 (K), SW18.1
unnamed: D18.1 (K), SW19.1
unnamed: D19.1 (K), SW20.1
unnamed: D20.1 (K), SW21.1
unnamed: D21.1 (K), SW22.1
unnamed: D22.1 (K), SW23.1
unnamed: D23.1 (K), SW24.1
unnamed: D24.1 (K), SW25.1
unnamed: D25.1 (K), SW26.1
unnamed: D26.1 (K), SW27.1
unnamed: D27.1 (K), SW28.1
unnamed: D28.1 (K), SW29.1
unnamed: D29.1 (K), SW30.1
unnamed: D30.1 (K), SW31.1
unnamed: D31.1 (K), SW32.1
unnamed: D32.1 (K), SW33.1
unnamed: D33.1 (K), SW34.1
unnamed: D34.1 (K), SW35.1
unnamed: D35.1 (K), SW36.1
unnamed: D36.1 (K), SW37.1
unnamed: D37.1 (K), SW38.1
unnamed: D38.1 (K), SW39.1
unnamed: D39.1 (K), SW40.1
unnamed: D40.1 (K), SW41.1
unnamed: D41.1 (K), SW42.1
unnamed: D42.1 (K), SW43.1
unnamed: D43.1 (K), SW44.1
unnamed: D44.1 (K), SW45.1
unnamed: D45.1 (K), SW46.1
unnamed: D46.1 (K), SW47.1
unnamed: D47.1 (K), SW48.1
unnamed: D48.1 (K), SW49.1
unnamed: D49.1 (K), SW50.1
unnamed: D50.1 (K), SW51.1
unnamed: D51.1 (K), SW52.1
unnamed: D52.1 (K), SW53.1
unnamed: D53.1 (K), SW54.1
unnamed: D54.1 (K), SW55.1
unnamed: U1.9 (QH'), U2.14 (SER)
unnamed: U2.9 (QH'), U4.14 (SER)
unnamed: SW17.1, U3.15 (RESET)
Parallel: U3.7 (PB08_A6_D6_TX), U7.1 (~PL)
R_Joystick_Bttn: R2.2, U3.6 (PA9_A5_D5_SCL), U6.B1A (SEL+), U6.H1 (H+), U6.V1 (V+)
R_Joystick_Horz: U3.4 (PA11_A3_D3), U6.H2 (H)
R_Joystick_Vert: U3.3 (PA10_A2_D2), U6.V2 (V)
Row 1: R7.2, SW1.2, SW4.2, SW8.2, SW12.2, SW18.2, SW23.2, SW30.2, SW35.2, SW40.2, SW45.2, SW49.2, SW53.2, U7.11 (D0)
Row 2: R6.2, SW2.2, SW5.2, SW9.2, SW13.2, SW19.2, SW24.2, SW31.2, SW36.2, SW41.2, SW46.2, SW50.2, SW54.2, U7.12 (D1)
Row 3: R5.2, SW3.2, SW6.2, SW10.2, SW14.2, SW20.2, SW25.2, SW28.2, SW29.2, SW32.2, SW37.2, SW42.2, SW47.2, SW51.2, SW55.2, U7.13 (D2)
Row 4: R4.2, SW7.2, SW11.2, SW15.2, SW21.2, SW26.2, SW33.2, SW38.2, SW43.2, SW48.2, SW52.2, U7.14 (D3)
Row 5: R3.2, SW16.2, SW22.2, SW27.2, SW34.2, SW39.2, SW44.2, U7.3 (D4)
SCK: U1.11 (SRCLK), U2.11 (SRCLK), U3.9 (PA7_A8_D8_SCK), U4.11 (SRCLK), U7.2 (CP)
Shift Register_1: U1.12 (RCLK), U2.12 (RCLK), U3.8 (PB09_A7_D7_RX), U4.12 (RCLK)

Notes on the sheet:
M C U
L R
J O Y S T I C K I N P U T' S L R
S H I F T R E G I S T E R S
S W I T C H M A T R I X

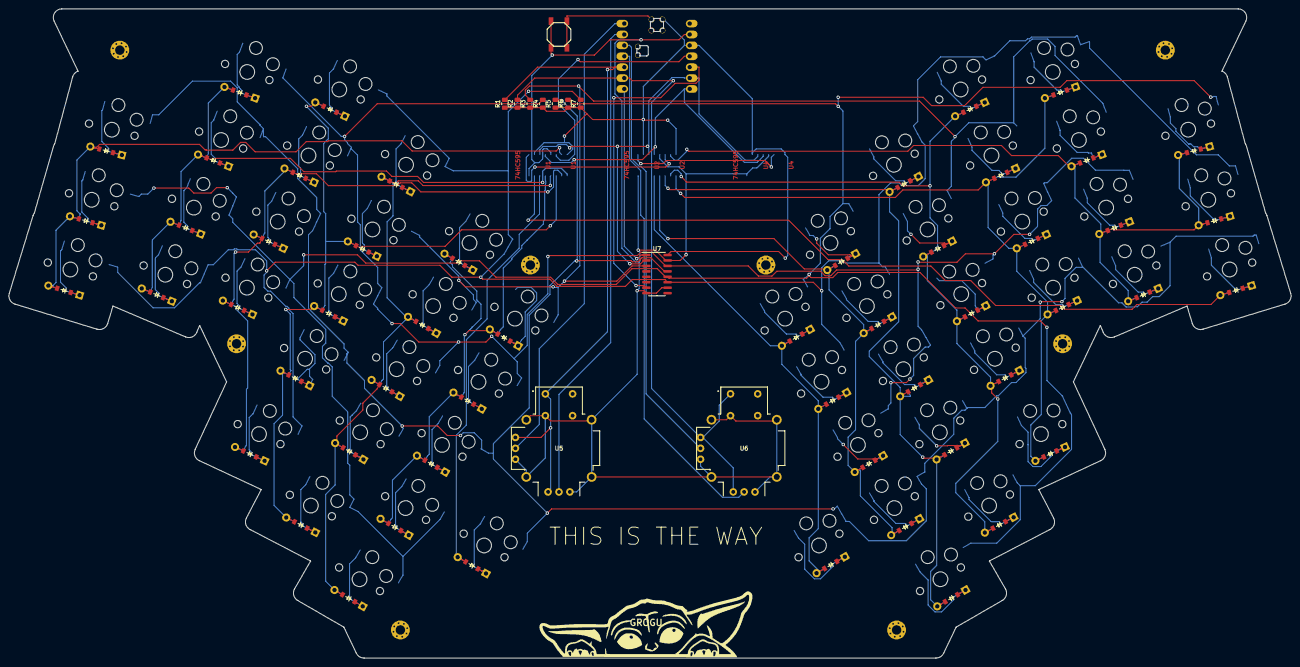
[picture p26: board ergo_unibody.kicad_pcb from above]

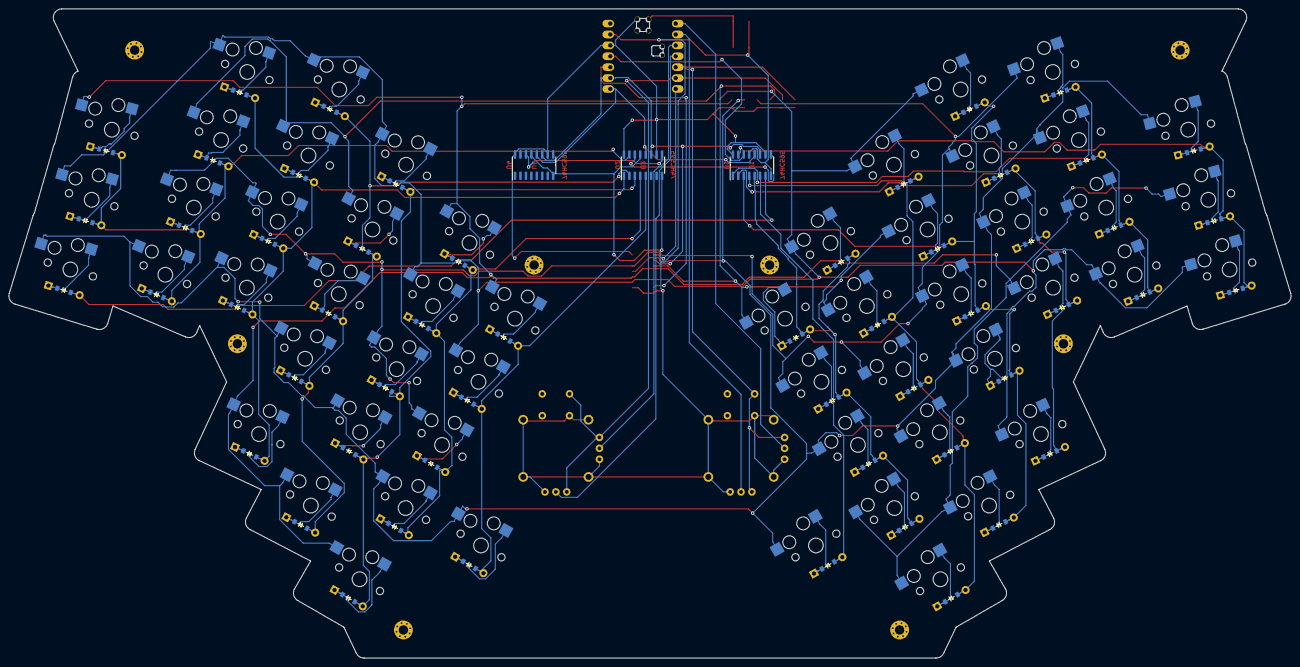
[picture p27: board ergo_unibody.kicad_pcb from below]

Board: 2 copper layers, 299.0 x 151.4 mm, 132 parts (3 on the bottom side), 89 nets.

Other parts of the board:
GROGU: LOGO; grogu_mod
_1, _2, _3, _4, _5, _6, _7, _8: MountingHole_2.2mm_M2_Pad_Via

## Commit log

2026-03-30 Initial commit: custom-keyboard hardware project
    [ergo_unibody-B_Cu.gbr, ergo_unibody-B_Mask.gbr, ergo_unibody-B_Paste.gbr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]
2026-03-30 Add images and pcb/schematics
